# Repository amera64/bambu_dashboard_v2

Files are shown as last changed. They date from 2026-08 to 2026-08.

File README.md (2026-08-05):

# Bambu Lab P1S Touchscreen Dashboard

A custom ESP32-S3 touchscreen dashboard for monitoring and controlling a Bambu Lab P1S printer over MQTT.

## Features

- Capacitive Touch Display
- Live print progress
- Printer status and current file
- Nozzle, bed, and chamber temperatures
- AMS slot colors and filament types
- Active filament path
- External spool status
- Pause and resume controls
- Chamber light control
- Automatic screen sleep and wake
- Web-based configuration
- Arduino OTA firmware updates
- Flip up display enclosure that retains use of original screen

## Screenshots

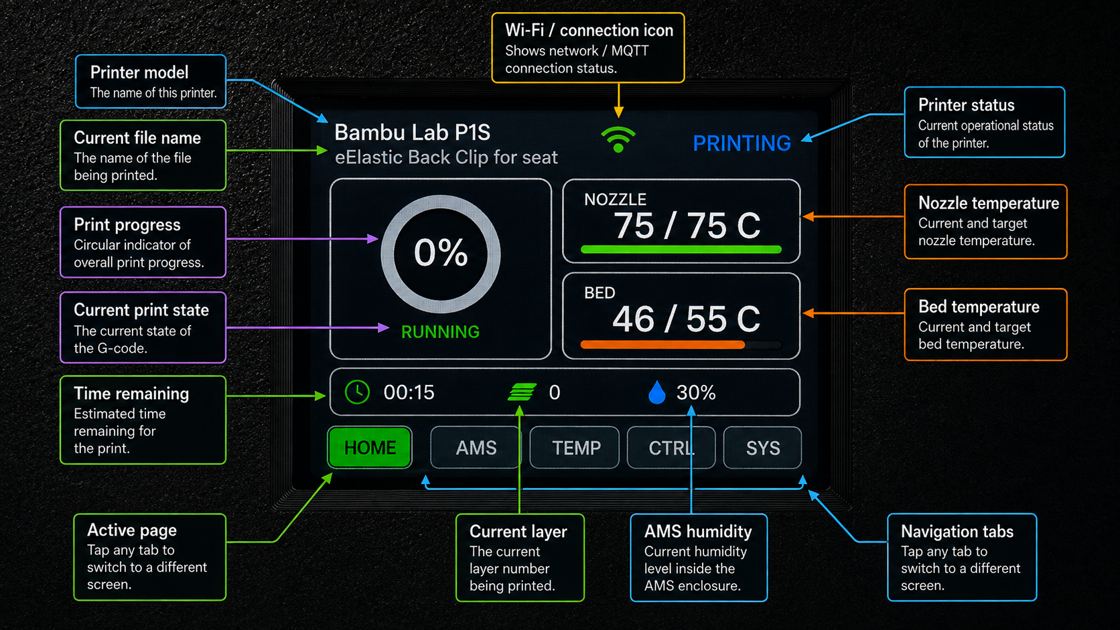
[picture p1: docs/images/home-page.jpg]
Home page


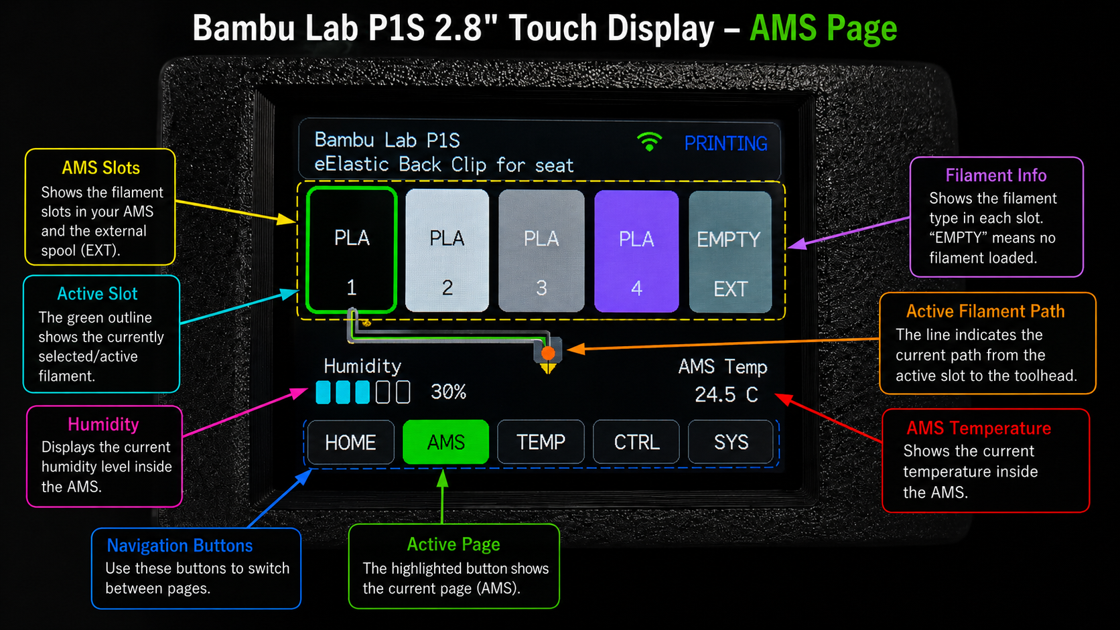
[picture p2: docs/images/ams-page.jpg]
AMS page


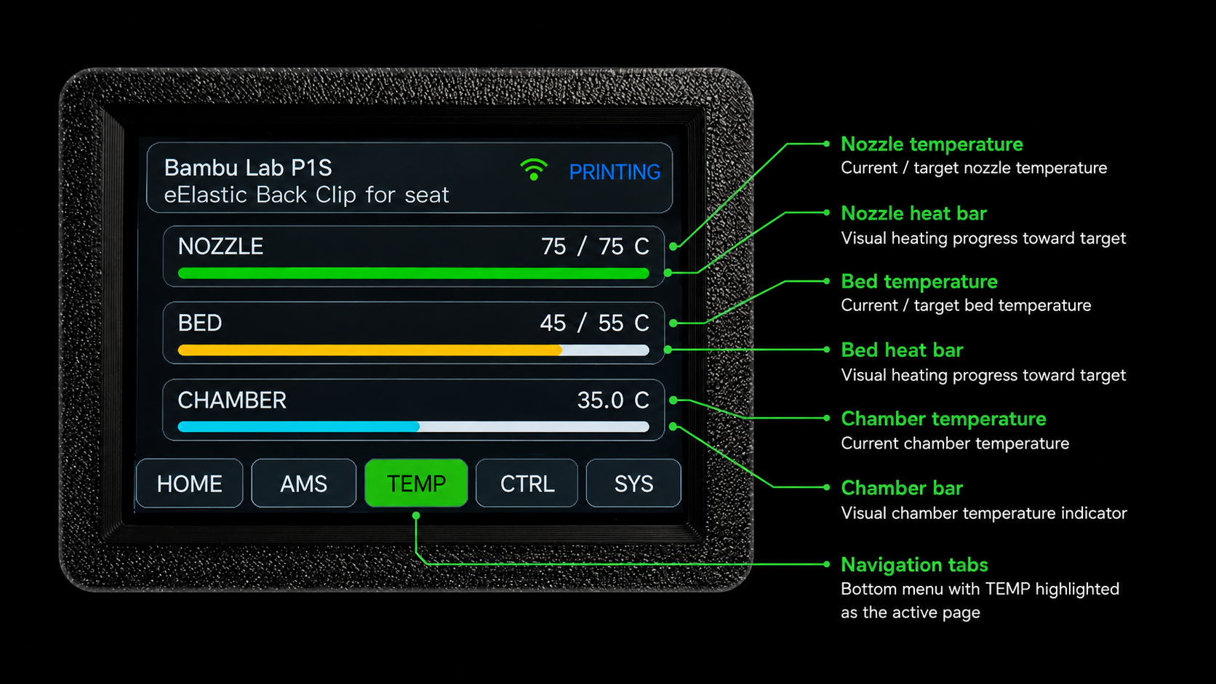
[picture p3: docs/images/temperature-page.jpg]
Temperature page


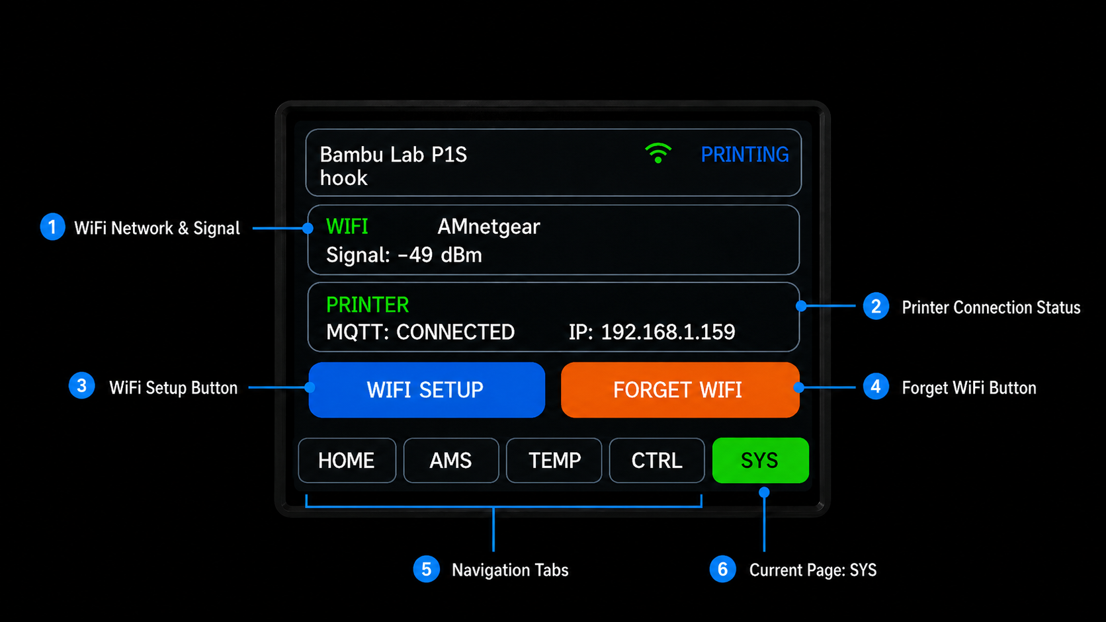
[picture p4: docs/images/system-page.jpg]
System page


## Web Admin Page

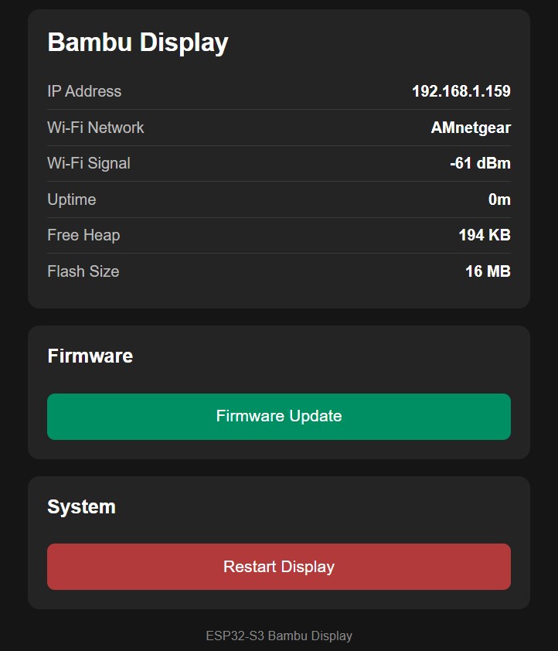
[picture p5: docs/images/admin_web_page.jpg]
Admin web page


## Flip Up Case

Case1

Case2

Case3

## Installation

See the complete [ESPHome Web installation instructions](INSTALLATION.md).

## Required Hardware

- [Freenove Capacitive Touch ESP32-S3 Display](https://www.amazon.com/dp/B0FSQF6FKN?th=1) *** Only tested with this display ***
- USB data cable
- Bambu Lab P1S printer
- Local network connection

## Support the Project

This project is available for personal and noncommercial use.

Contributions are optional and help cover development hardware, test displays,
prototype enclosures, and continued firmware improvements.



## Important

This is an independent community project and is not affiliated with Bambu Lab.

## License

Copyright © 2026 Alan [Last Name].

The source code and compiled firmware in this repository are licensed
under the PolyForm Noncommercial License 1.0.0.

Personal, hobby, educational, and other noncommercial use is permitted.

Commercial use is not permitted without prior written permission from
the copyright holder. This includes selling displays containing this
firmware, selling modified versions, charging for copies, or including
the software in a paid product.

Commercial licensing inquiries: your-email@example.com

Third-party libraries and components remain subject to their respective
licenses.

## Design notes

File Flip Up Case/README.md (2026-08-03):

# Bambu Dashboard 3D-Printable Enclosure

This enclosure was designed for the 2.8-inch ESP32-S3 touchscreen used by the Bambu P1S Dashboard project.

## Included Parts

- `2.8 inch ESP32 Flip up Display case back.stl`
- `2.8 inch ESP32 Flip up Display case front.stl`
- `2.8 inch ESP32 Flip up Display_adaptor.stl`

Editable STEP files are also included for users who want to customize the enclosure.

## Recommended Print Settings

- Material: PLA or PETG
- Layer height: 0.20 mm
- Walls: 3
- Top and bottom layers: 4
- Infill: 15–20%
- Supports: None, unless required by your printer or orientation
- Brim: Optional

## Suggested Orientation

Print both pieces with their largest flat surface against the build plate.

## Parts Needed
A USB-A to USB-B micro cable approxmately 200mm in length is ideal. I speculate that a cable as short as 150mm might just reach,
and if the cable was longer, the enclosure has space to tuck in the excess.

6 x M3 x 12mm countersunk bolts for attaching the rear to the front pieces.

2 x M3 x 12mm bolts for attaching the enclosure to the adaptor.

## Assembly

1. Insert the display into the front bezel.
2. Make sure the screen and USB connector are correctly aligned.
3. Secure the circuit board to the internal mounting posts.
4. Route the USB cable through the enclosure opening.
5. Install the rear cover using the appropriate screws.
6. Do not overtighten the screws, as this may damage the printed mounting posts.

## Compatibility

This enclosure is designed specifically for the display model identified in the main project documentation. Other ESP32-S3 displays may use different board dimensions, connector locations, or mounting-hole spacing.

## License

The enclosure files are provided for personal and noncommercial use only. Commercial use, redistribution for sale, or selling printed enclosures based on these files requires written permission from the copyright holder.

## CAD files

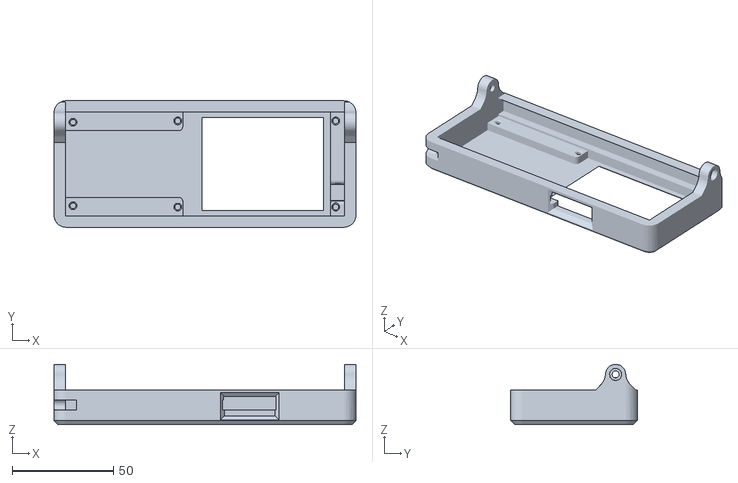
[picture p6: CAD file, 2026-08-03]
Flip Up Case/2.8 inch ESP32 Flip up Display case front.stl
149.1 x 62.5 x 29.8

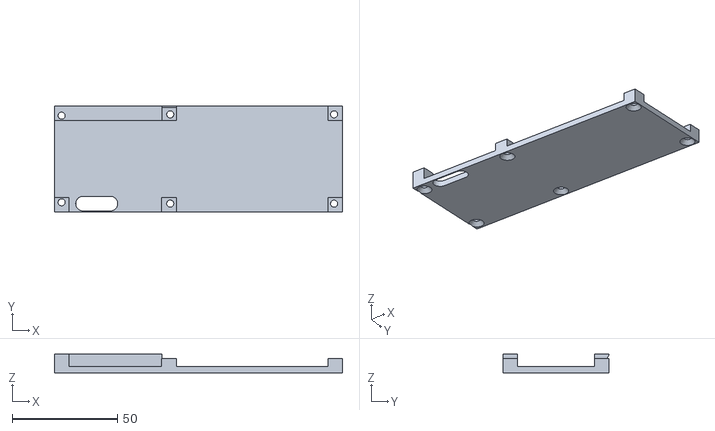
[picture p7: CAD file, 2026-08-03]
Flip Up Case/2.8 inch ESP32 Flip up Display case back.stl
137.1 x 50.5 x 9.00

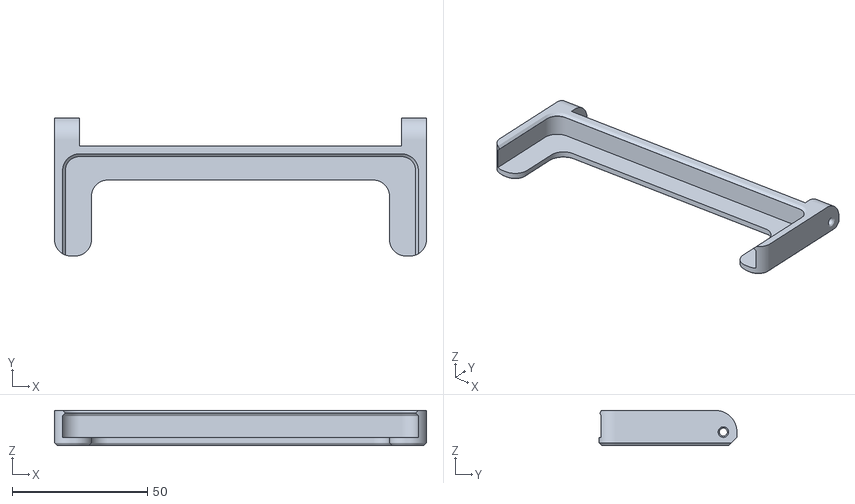
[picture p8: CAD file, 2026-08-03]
Flip Up Case/2.8 inch ESP32 Flip up Display_adaptor.stl
137.3 x 50.9 x 13.0

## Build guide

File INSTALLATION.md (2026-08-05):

Use the official ESPHome Web installer here:

https://web.esphome.io/

In your instructions, that section can read:

1. Open Google Chrome or Microsoft Edge.
2. Go to https://web.esphome.io/
3. Connect the display with a USB data cable.
4. Click Connect.
5. Select the ESP32-S3 COM port.
6. Click Install and choose the merged dashboard .bin file.
7. Wait for the installation to finish before unplugging the display.

## First-Time Wi-Fi Configuration

Use this procedure after installing the firmware on a new display.

Before You Begin

Have the following information available:

1. Your home Wi-Fi network name
2. Your Wi-Fi password
3. Your Bambu Lab P1S printer’s IP address
   
   Finding the Printer IP Address
   The printer IP address can be found on the Bambu Lab P1S touchscreen:
   Open the printer’s settings. Open the network or LAN information page. Locate the printer’s IP address.
   The display and printer must normally be connected to the same local network.
   
5. A phone, tablet, or computer with Wi-Fi

The ESP32-S3 display connects to 2.4 GHz Wi-Fi. Make sure your network provides a 2.4 GHz connection.

1. Start Wi-Fi Setup Mode
2. Power on the display.
3. Open the SYS page using the bottom navigation bar.
4. Tap WIFI SETUP.
   
The display will show:
WiFi Setup Mode

Connect your phone to:
Bambu_P1S_Setup

Then open:
192.168.4.1 (username: admin password: bambuupdate)

The display temporarily disconnects from your home network and creates its own Wi-Fi setup network.

2. Connect to the Display

On your phone, tablet, or computer:

Open the device’s Wi-Fi settings.
Select:
Bambu_P1S_Setup
Connect to the network.

The setup network does not require a password.

Your device may warn that the network has no internet connection. Choose the option to remain connected.

On some phones, temporarily turning off mobile data prevents the phone from leaving the setup network.

3. Open the Setup Page

Open Chrome, Edge, Safari, or another web browser and enter:

http://192.168.4.1

Be sure to include:

http://

The Bambu P1S Setup page should appear.

4. Enter the Wi-Fi Information

On the setup page:

Select your home Wi-Fi network from the WiFi Network list.
Enter the Wi-Fi password.
Enter the IP address of your Bambu Lab P1S printer.

Example:

192.168.1.159
Tap SAVE.

Wi-Fi passwords are case-sensitive. Enter uppercase letters, lowercase letters, numbers, and symbols exactly as they appear in the router settings.

5. Wait for the Display to Restart

After pressing SAVE, the page will show:

Settings Saved
Restarting...

The display will save the following information:

Wi-Fi network name
Wi-Fi password
Printer IP address

The display will then restart automatically.

6. Reconnect Your Phone or Computer

Because the temporary setup network shuts down during the restart:

Open your phone or computer’s Wi-Fi settings.
Reconnect to your normal home Wi-Fi network if it does not reconnect automatically.
7. Confirm the Connection

After the display restarts, open the SYS page.

Confirm that it shows:

Your Wi-Fi network name
A valid display IP address
Wi-Fi signal strength
MQTT status as connected

The dashboard may take several seconds to connect to the printer and receive its initial status.

Finding the Printer IP Address

The printer IP address can be found on the Bambu Lab P1S touchscreen:

Open the printer’s settings.
Open the network or LAN information page.
Locate the printer’s IP address.

The display and printer must normally be connected to the same local network.

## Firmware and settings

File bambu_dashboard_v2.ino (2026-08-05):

#include <Arduino.h>
#include <ArduinoOTA.h>

#include "PrinterData.h"
#include "LGFX_Config.h"
#include "Config.h"
#include "UI.h"
#include "MQTT.h"
#include "WiFiSetup.h"
#include "Settings.h"
#include "SleepManager.h"
#include "WebAdmin.h"
#include <WiFi.h>
#include "SystemStatus.h"

#include "UIUpdateFlags.h"
#include "HomePage.h"
#include "AMSPage.h"
#include "ControlPage.h"
#include "SystemPage.h"
#include "TemperaturePage.h"


LGFX lcd;

int currentPage = 0;
bool temperatureDisplayChanged = false;
String printerState = "ONLINE";

volatile bool displayWakeRequested = false;


void setupOTA()
{
    ArduinoOTA.setHostname("bambu-display");

    // Optional but strongly recommended
    ArduinoOTA.setPassword("malibu2515");

    ArduinoOTA.onStart([]()
    {
        Serial.println("OTA update starting");

        // Keep the display awake during the update
        requestScreenWake();

        lcd.fillScreen(TFT_BLACK);
        lcd.setTextDatum(middle_center);
        lcd.setFont(&fonts::Font2);
        lcd.setTextColor(TFT_WHITE);
        lcd.drawString(
            "UPDATING FIRMWARE",
            lcd.width() / 2,
            lcd.height() / 2 - 10
        );
    });

    ArduinoOTA.onProgress([](
        unsigned int progress,
        unsigned int total)
    {
        const int percent =
            static_cast<int>(
                (progress * 100ULL) / total
            );

        lcd.fillRect(
            80,
            lcd.height() / 2 + 10,
            160,
            25,
            TFT_BLACK
        );

        lcd.setTextDatum(middle_center);
        lcd.setTextColor(TFT_WHITE);
        lcd.drawString(
            String(percent) + "%",
            lcd.width() / 2,
            lcd.height() / 2 + 20
        );
    });

    ArduinoOTA.onEnd([]()
    {
        Serial.println("OTA update complete");

        lcd.fillScreen(TFT_BLACK);
        lcd.setTextDatum(middle_center);
        lcd.setTextColor(TFT_GREEN);
        lcd.drawString(
            "UPDATE COMPLETE",
            lcd.width() / 2,
            lcd.height() / 2
        );
    });

    ArduinoOTA.onError([](ota_error_t error)
    {
        Serial.print("OTA error: ");
        Serial.println(error);

        lcd.fillScreen(TFT_BLACK);
        lcd.setTextDatum(middle_center);
        lcd.setTextColor(TFT_RED);
        lcd.drawString(
            "UPDATE FAILED",
            lcd.width() / 2,
            lcd.height() / 2
        );
    });

    ArduinoOTA.begin();

    Serial.print("OTA ready at: ");
    Serial.println(WiFi.localIP());
}


void setup()
{
    Serial.begin(115200);


    delay(1000);

    Serial.print("Reset reason number: ");
    Serial.println((int)esp_reset_reason());


    randomSeed(micros());

    lcd.init();
    lcd.setRotation(3);
    lcd.setBrightness(255);
    initSleepManager();

    drawHome();

    // Load WiFi settings from storage
    loadSettings();

    if (wifiSSID.length() == 0)
    {
        Serial.println("No WiFi settings found");
        startWiFiSetup();
    }
    else
    {
        setupWiFi();

        if (WiFi.status() == WL_CONNECTED)
        {
            setupOTA();
        }
    }


    initWebAdmin();
    Serial.print("Admin IP: ");
    Serial.println(WiFi.localIP());
    Serial.print("WiFi status: ");
    Serial.println(WiFi.status());
    
    setupMQTT();
    startMQTTTask();
    Serial.println("Bambu Dashboard V2 Started");
}

void loop()
{


    static unsigned long lastHeartbeatCheck = 0;
    static bool lastMQTTState = false;
    static bool printerWasOnline = false;

    // Web server, touch, and display stay on the Arduino loop
    if (wifiSetupActive)
    {
        handleWiFiServer();
    }
    else
    {
        updateWebAdmin();
    }

    ArduinoOTA.handle();
    updateSleepManager();
    handleTouch();
  

    if (displayWakeRequested)
    {
        displayWakeRequested = false;

        requestScreenWake();
    }

    // MQTT runs independently on Core 0
    bool currentMQTTState =
        systemStatus.mqttConnected;

    if (currentMQTTState != lastMQTTState)
    {
        lastMQTTState =
            currentMQTTState;

        updateMQTTIcon();

        // Redraw the header when MQTT changes state
        pageChanged = true;
    }

    // Check printer heartbeat once per second
    if (
        millis() - lastHeartbeatCheck >= 1000
    )
    {
        lastHeartbeatCheck =
            millis();

        bool printerOnline =
            currentMQTTState &&
            lastPrinterUpdate != 0 &&
            millis() - lastPrinterUpdate <= 10000;

        if (
            printerOnline !=
            printerWasOnline
        )
        {
            printerWasOnline =
                printerOnline;

            pageChanged = true;

            Serial.print(
                "Printer status changed: "
            );

            Serial.println(
                printerOnline
                    ? "ONLINE"
                    : "OFFLINE"
            );
        }
    }

    // Full redraw only for page changes
    if (pageChanged)
    {
        Serial.print("Full page redraw: ");
        Serial.println(currentPage);

        drawUI();

        pageChanged = false;

        // The full redraw already refreshed everything
        clearAllUIUpdates();
    }
    else
    {
        // Partial updates only
        if (uiUpdates.header)
        {
            drawHeader();
            uiUpdates.header = false;
        }

        if (currentPage == HOME_PAGE)
        {
            if (uiUpdates.progress)
            {
                updateHomeProgress();
                uiUpdates.progress = false;
            }
            
            if (uiUpdates.progressStatus)
            {
                updateHomeProgressStatus();
                uiUpdates.progressStatus = false;
            }

            if (uiUpdates.nozzle)
            {
                updateHomeNozzle();
                uiUpdates.nozzle = false;
            }

            if (uiUpdates.bed)
            {
                updateHomeBed();
                uiUpdates.bed = false;
            }

            if (uiUpdates.bottomInfo)
            {
                updateHomeBottomInfo();
                uiUpdates.bottomInfo = false;
            }
        }
        else if (currentPage == AMS_PAGE)
        {
            if (uiUpdates.ams)
            {
                drawAMS();
                uiUpdates.ams = false;
            }
        }
        else if (currentPage == CONTROL_PAGE)
        {
            if (uiUpdates.controls)
            {
                drawPrintControl();
                drawNavigation();

                uiUpdates.controls = false;
            }
        }
        else if (currentPage == SYS_PAGE)
        {
            if (uiUpdates.system)
            {
                drawSystem();
                uiUpdates.system = false;
            }
        }

        else if (currentPage == TEMP_PAGE)
        {
            if (uiUpdates.tempNozzle)
            {
                updateTemperatureNozzle();
                uiUpdates.tempNozzle = false;
            }

            if (uiUpdates.tempBed)
            {
                updateTemperatureBed();
                uiUpdates.tempBed = false;
            }

            if (uiUpdates.tempChamber)
            {
                updateTemperatureChamber();
                uiUpdates.tempChamber = false;
            }
        }
    }

    if (temperatureDisplayChanged)
    {
        uiUpdates.nozzle = true;
        uiUpdates.bed = true;

        temperatureDisplayChanged = false;
    }

    // Small yield for background system processing
    delay(1);
}

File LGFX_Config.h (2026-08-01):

#pragma once

#include <LovyanGFX.hpp>

class LGFX : public lgfx::LGFX_Device
{

  lgfx::Panel_ILI9341 _panel;
  lgfx::Bus_SPI _bus;
  lgfx::Light_PWM _light;
  lgfx::Touch_FT5x06 _touch;

public:

  LGFX(void)
  {

    // SPI BUS CONFIGURATION
    {
      auto cfg = _bus.config();

      cfg.spi_host = SPI2_HOST;
      cfg.spi_mode = 3;

      cfg.freq_write = 80000000;
      cfg.freq_read  = 16000000;

      cfg.pin_sclk = 12;   // CHANGE
      cfg.pin_mosi = 11;   // CHANGE
      cfg.pin_miso = 13;

      cfg.pin_dc = 46;     // CHANGE

      _bus.config(cfg);
      _panel.setBus(&_bus);
    }


    // DISPLAY PANEL CONFIGURATION
    {
      auto cfg = _panel.config();

      cfg.pin_cs  = 10;     // CHANGE
      cfg.pin_rst = -1;     // CHANGE

      cfg.panel_width  = 240;
      cfg.panel_height = 320;

      cfg.memory_width  = 240;
      cfg.memory_height = 320;

      cfg.offset_rotation = 0;

      cfg.dummy_read_pixel = 8;
      cfg.dummy_read_bits  = 1;

      cfg.readable = false;
      cfg.invert = true;

      _panel.config(cfg);
    }


    // BACKLIGHT CONFIGURATION
    {
      auto cfg = _light.config();

      cfg.pin_bl = 45;       // CHANGE to your BL pin
      cfg.invert = false;

      cfg.freq = 44100;
      cfg.pwm_channel = 7;

      _light.config(cfg);

      _panel.setLight(&_light);
    }

    // TOUCH CONFIGURATION (FT6x36)
    {
      auto cfg = _touch.config();

      cfg.i2c_port = 0;
      cfg.i2c_addr = 0x38;

      cfg.pin_sda = 16;   // CHANGE if your board uses different pins
      cfg.pin_scl = 15;   // CHANGE if your board uses different pins

      cfg.pin_int = -1;
      cfg.pin_rst = -1;

      cfg.x_min = 0;
      cfg.x_max = 239;
      cfg.y_min = 0;
      cfg.y_max = 319;

      _touch.config(cfg);

      _panel.setTouch(&_touch);
    }

    setPanel(&_panel);

  }

};

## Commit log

2026-08-01 Update bambu_dashboard_v2.ino
    Flip display orientation 180 degrees
    [bambu_dashboard_v2.ino]
2026-08-02 Added OTA updates and other fixes
    1-Added OTA firmware uploading
    2-Fixed status to not display UNKNOWN after reboots
    3-Fixed external spool card to display ? for no color selected and "EMPTY" when not active.
    [MQTT.cpp, bambu_dashboard_v2.ino]
2026-08-03 Added 3D print files
    [2.8 inch ESP32 Flip up Display case back.stl, 2.8 inch ESP32 Flip up Display case front.stl, 2.8 inch ESP32 Flip up Display_adaptor.stl]
2026-08-05 Added web admin fields for printer serial number and access code.
2026-08-05 Added printer access code, and serial number fields in web admin page.
